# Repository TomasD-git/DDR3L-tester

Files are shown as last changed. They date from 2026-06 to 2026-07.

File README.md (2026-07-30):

# DDR3L-tester  
**Very simple DDR3L tester, plug ddr3l stick into slot, esp32 c6 reads data and can overwrite config of ram as well, with buttons for control and screen to see progress**  

<details>
<summary>How to make one?</summary>
  
**Either buy PCBA which is much easier but much more expenisve, or buy all parts and assemble with hotplate or hotair gun. all files needed for this are in production folder**  

</details>

<details>
<summary>How assemble?</summary>
Place top part ontop of the pcb and solder screen and buttons, then place the bottom part underneath the pcb and use M2 screws to screw into place.  

</details>

<details>
<summary>How to flash?</summary>
Plug the USB-C into computer and use arduino ide to flash.  

</details>

<details>
<summary>BOM</summary>

| Name | Purpose | Quantity | Total Cost (USD) | Link | Distributor |
| --- | --- | --- | --- | --- | --- |
| PCB + stencil if needed | all components are on this | 1 | 20 | https://jlcpcb.com | jlcpcb |
| ALL components | all components that are on pcb | 1 | 40 | https://lcsc.com | lcsc |
| Screen | shows info numbers etc.. | 1 | 3 | https://www.aliexpress.com/item/1005006141235306.html | Aliexpress |
| | | **Total cost** | **63** | | |

</details>

    
  
  
  


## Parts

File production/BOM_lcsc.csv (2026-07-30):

JLCPCB BOM Tool - BOM Matching
BOM name：bom-JLCPCB Assembly Order.xlsx |  |  | Download Time：2026-06-09 15:07:55 |  |  |  | * Our matching results are updated in real-time, but stock and prices may change. If it's been over 24 hours, please re-match before placing your order.
PCB Assembled Qty：5 |  |  | Est. Total Price：46.1511
Your BOM |  |  |  |  | Matched Parts |  |  |  |  |  |  | Order Information
Top Designator | Bottom Designator | Comment | Footprint | JLCPCB Part # | Matches | Part # | Manufacturer | Footprint | Description | Category | Warning | JLCPCB Part # | Product link | Lib Type | Qty | Source | Total Price ($)
C1,C10,C19,C20,C5 |  | 100nF | 0805 |  | Select by System | CC0805KRX7R9BB104 | YAGEO | 0805 | 100nF 50V X7R ±10% 0805 Multilayer Ceramic Capacitors MLCC - SMD/SMT ROHS | Multilayer Ceramic Capacitors MLCC - SMD/SMT |  | C49678 | https://jlcpcb.com/partdetail/YAGEO-CC0805KRX7R9BB104/C49678 | Basic | 35 | 35 JLCPCB | 0.2975
C2 |  | 47uF | 1210 |  | Select by System | CS3225X7R476K100NRL | Samwha Capacitor | 1210 | 10V 47uF X7R ±10% 1210 Multilayer Ceramic Capacitors MLCC - SMD/SMT ROHS | Multilayer Ceramic Capacitors MLCC - SMD/SMT |  | C5189825 | https://jlcpcb.com/partdetail/5869646-CS3225X7R476K100NRL/C5189825 | Extended | 9 | 9 JLCPCB | 0.8595
C3,C7 |  | 10uF | 0805 |  | Select by System | GRM21BR61H106KE43L | Murata Electronics | 0805 | 10uF 50V X5R ±10% 0805 Multilayer Ceramic Capacitors MLCC - SMD/SMT ROHS | Multilayer Ceramic Capacitors MLCC - SMD/SMT |  | C440198 | https://jlcpcb.com/partdetail/439567-GRM21BR61H106KE43L/C440198 | Basic | 10 | 10 JLCPCB | 3.083
C8,C9 |  | 1nF | 0805 |  | Select by System | CL21B102KBCNNNC | Samsung Electro-Mechanics | 0805 | 1nF 50V X7R ±10% 0805 Multilayer Ceramic Capacitors MLCC - SMD/SMT ROHS | Multilayer Ceramic Capacitors MLCC - SMD/SMT |  | C46653 | https://jlcpcb.com/partdetail/47657-CL21B102KBCNNNC/C46653 | Basic | 20 | 20 JLCPCB | 0.224
C21,C4,C6 |  | 1uF | 0805 |  | Select by System | CL21B105KBFNNNE | Samsung Electro-Mechanics | 0805 | 1uF 50V X7R ±10% 0805 Multilayer Ceramic Capacitors MLCC - SMD/SMT ROHS | Multilayer Ceramic Capacitors MLCC - SMD/SMT |  | C28323 | https://jlcpcb.com/partdetail/29074-CL21B105KBFNNNE/C28323 | Basic | 25 | 25 JLCPCB | 0.4325
D1 |  | GREENLED | LED_D5.0mm |  | Select by Customer | TJ-L5FYTGHKMCGLFLC7K-A5 | TOGIALED | 插件,D=5mm | -20℃~+80℃ 1.8V~2.6V 20mA 45° 565nm~575nm 575nm 5mm round lamp head 60mcd 72mW Green Diffused Lens Yellow Green 插件,D=5mm LED Indication - Discrete ROHS | LED Indication - Discrete |  | C330740 | https://jlcpcb.com/partdetail/TOGIALED-TJ_L5FYTGHKMCGLFLC7KA5/C330740 | Extended | 6 | 6 JLCPCB | 0.2502
D2 |  | REDLED | LED_D5.0mm |  | Select by Customer | 333-2SURD/S530-A3 | Everlight Elec | 插件,D=5mm | -40℃~+85℃ 200mcd 20mA 2V 30° 5mm round lamp head 624nm 632nm Red Red Lens 插件,D=5mm LED Indication - Discrete ROHS | LED Indication - Discrete |  | C87271 | https://jlcpcb.com/partdetail/EverlightElec-333_2SURD_S530A3/C87271 | Extended | 10 | 10 JLCPCB | 0.417
R1,R10,R9 |  | 10K | 0805 |  | Unconfirmed | 0805W8F1002T5E | UNI-ROYAL(Uniroyal Elec) | 0805 | -55℃~+155℃ 10kΩ 125mW 150V Thick Film Resistor ±1% ±100ppm/℃ 0805 Chip Resistor - Surface Mount ROHS | Chip Resistor - Surface Mount | 1.The comment (0805W8F1002T5E) of this part does not match the one (10K) provided in your BOM. Please confirm; | C17414 | https://jlcpcb.com/partdetail/18102-0805W8F1002T5E/C17414 | Basic | 25 | 25 JLCPCB | 0.0725
R2,R3 |  | 330 | 0805 |  | Unconfirmed | 0805W8F3300T5E | UNI-ROYAL(Uniroyal Elec) | 0805 | -55℃~+155℃ 125mW 150V 330Ω Thick Film Resistor ±1% ±100ppm/℃ 0805 Chip Resistor - Surface Mount ROHS | Chip Resistor - Surface Mount | 1.The comment (0805W8F3300T5E) of this part does not match the one (330) provided in your BOM. Please confirm; | C17630 | https://jlcpcb.com/partdetail/18318-0805W8F3300T5E/C17630 | Basic | 20 | 20 JLCPCB | 0.054
R11,R12 |  | 22 | 0805 |  | Unconfirmed | 0805W8F220JT5E | UNI-ROYAL(Uniroyal Elec) | 0805 | -55℃~+155℃ 125mW 150V 22Ω Thick Film Resistor ±1% ±100ppm/℃ 0805 Chip Resistor - Surface Mount ROHS | Chip Resistor - Surface Mount | 1.The comment (0805W8F220JT5E) of this part does not match the one (22) provided in your BOM. Please confirm; | C17561 | https://jlcpcb.com/partdetail/18249-0805W8F220JT5E/C17561 | Basic | 20 | 20 JLCPCB | 0.054
R13,R14 |  | 5.1K | 0805 |  | Unconfirmed | 0805W8F5101T5E | UNI-ROYAL(Uniroyal Elec) | 0805 | -55℃~+155℃ 125mW 150V 5.1kΩ Thick Film Resistor ±1% ±100ppm/℃ 0805 Chip Resistor - Surface Mount ROHS | Chip Resistor - Surface Mount | 1.The comment (0805W8F5101T5E) of this part does not match the one (5.1K) provided in your BOM. Please confirm; | C27834 | https://jlcpcb.com/partdetail/28584-0805W8F5101T5E/C27834 | Basic | 20 | 20 JLCPCB | 0.054
R15,R16 |  | 4.7K | 0805 |  | Unconfirmed | 0805W8F4701T5E | UNI-ROYAL(Uniroyal Elec) | 0805 | -55℃~+155℃ 125mW 150V 4.7kΩ Thick Film Resistor ±1% ±100ppm/℃ 0805 Chip Resistor - Surface Mount ROHS | Chip Resistor - Surface Mount | 1.The comment (0805W8F4701T5E) of this part does not match the one (4.7K) provided in your BOM. Please confirm; | C17673 | https://jlcpcb.com/partdetail/18361-0805W8F4701T5E/C17673 | Basic | 20 | 20 JLCPCB | 0.044
SW1,SW2 |  | SW_Push | SW_PUSH_6mm |  | Select by Customer | TC-00104-050E | HOOYA | 插件,6x6mm | 2.5N 5mm 6mm 6mm Black No PC Pin Round Button SPST Through Hole Without Bracket Plugin,6x6mm Tactile Switches ROHS | Tactile Switches |  | C2939600 | https://jlcpcb.com/partdetail/HOOYA-TC_00104050E/C2939600 | Extended | 10 | 10 JLCPCB | 0.229
SW3 |  | RotaryEncoder_Switch_MP | RotaryEncoder_Alps_EC11E-Switch_Vertical_H20mm |  | Select by Customer | EC11E1834403 | ALPSALPINE | 插件 | -40℃~+85℃ 10mA 5V Non-resettable Straight Support Two-phase output 插件 Rotary Encoders ROHS | Rotary Encoders |  | C361165 | https://jlcpcb.com/partdetail/ALPSALPINE-EC11E1834403/C361165 | Extended | 5 | 5 JLCPCB | 10.1695
SW6 |  | SS-12D00-G4E | 1P2T_SS-12D00_CNK |  | Select by Customer | SS-12D00-G3 | SOFNG | 插件-3P,8.8x3.9mm | -35℃~+75℃ 3.9mm 7.2mm 8.8mm Black PC Pin Rectangular Columnar SPDT Through Hole 插件-3P,8.8x3.9mm Slide Switches ROHS | Slide Switches |  | C22355741 | https://jlcpcb.com/partdetail/SOFNG-SS_12D00G3/C22355741 | Extended | 6 | 6 JLCPCB | 0.351
U2 |  | XDAP-4042044-20401 | CONN-SMD_204P-P0.60_XDAP-4042044-20401 |  | Select by System | XDAP-4042044-20401 | Lian Xin Technology | SMD | 204P 5.2mm DDR3 SO-DIMM Surface Mount SMD Memory Connector (DDR) ROHS | Memory Connector (DDR) |  | C22471982 | https://jlcpcb.com/partdetail/24195375-XDAP_404204420401/C22471982 | Extended | 5 | 5 JLCPCB | 7.78
U3 |  | AP2112K-3.3TRG1 | SOT-25-5_L2.9-W1.6-P0.95-LS2.8-BL |  | Select by System | AP2112K-3.3TRG1 | Diodes Incorporated | SOT-25-5 | -40℃~+85℃@(Ta) 1 250mV@(600mA) 3.3V 50uVrms 55uA 600mA 65dB@(1kHz) 6V Fixed Over Current Protection、Thermal Shutdown、Enable control Positive SOT-25-5 Voltage Regulators - Linear, Low Drop Out (LDO) Regulators ROHS | Voltage Regulators - Linear, Low Drop Out (LDO) Regulators |  | C51118 | https://jlcpcb.com/partdetail/DiodesIncorporated-AP2112K_33TRG1/C51118 | Extended | 7 | 7 JLCPCB | 1.1375
U4 |  | ESP32-C6-MINI-1/U | ESP32-C6-MINI-1 |  | Select by Customer | ESP32-C6-MINI-1-N4 | Espressif Systems | SMD-53P | -106dBm -40℃~+85℃ 2.4GHz 21dBm 354mA 3V~3.6V 71mA ESP32-C6FH4 On-board PCB Antenna UART、SPI、I2C、GPIO、I2S SMD-53P WiFi Modules ROHS | WiFi Modules |  | C5736265 | https://jlcpcb.com/partdetail/EspressifSystems-ESP32_C6_MINI_1N4/C5736265 | Extended | 5 | 5 JLCPCB | 20.2015
USB1 |  | TYPE-C16PIN2MD | USB-C-SMD_TYPE-C-16PIN-2MD-073 |  | Select by System | TYPE-C 16PIN 2MD(073) | SHOU HAN | SMD | -25℃~+85℃ 1 16P 3A 5,000 times 5V Black Female Surface Mount, Right Angle Type-C SMD USB Connectors ROHS | USB Connectors |  | C2765186 | https://jlcpcb.com/partdetail/SHOUHAN-TYPE_C_16PIN_2MD_073/C2765186 | Extended | 6 | 6 JLCPCB | 0.4404
J1 |  | 128x64LCDDisplay | PinSocket_1x04_P2.54mm_Vertical |  | No matches | No Part Selected
SW4,SW5 |  | SW_Push | SW_Cherry_MX_1.00u_PCB |  | No matches | No Part Selected

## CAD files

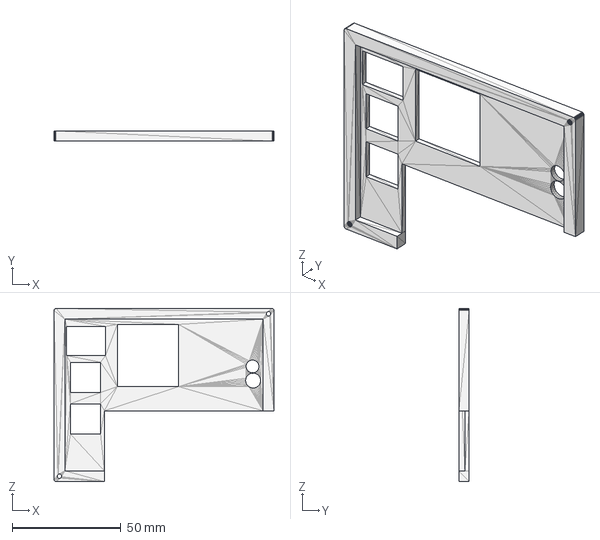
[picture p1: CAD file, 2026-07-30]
CAD/Top.step
101.3 x 4.75 x 79.8 mm

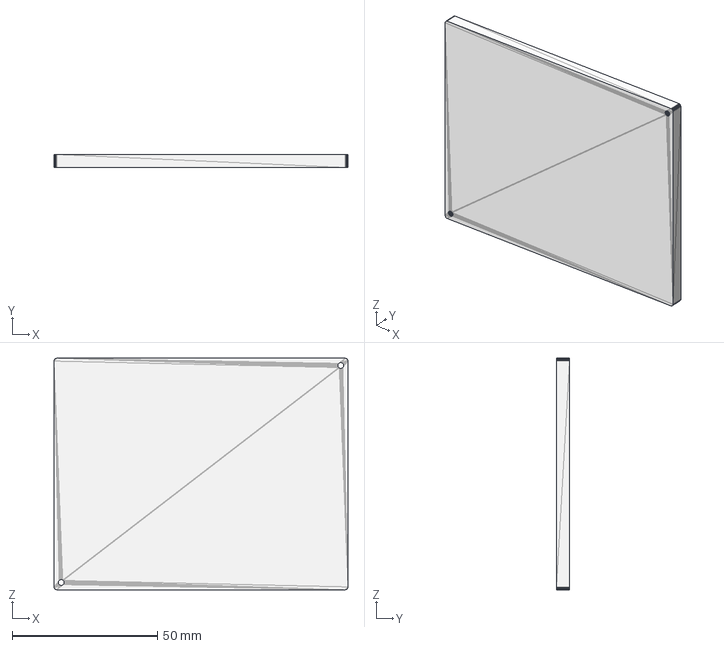
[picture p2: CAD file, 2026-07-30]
CAD/Bottom.step
101.3 x 4.50 x 79.8 mm

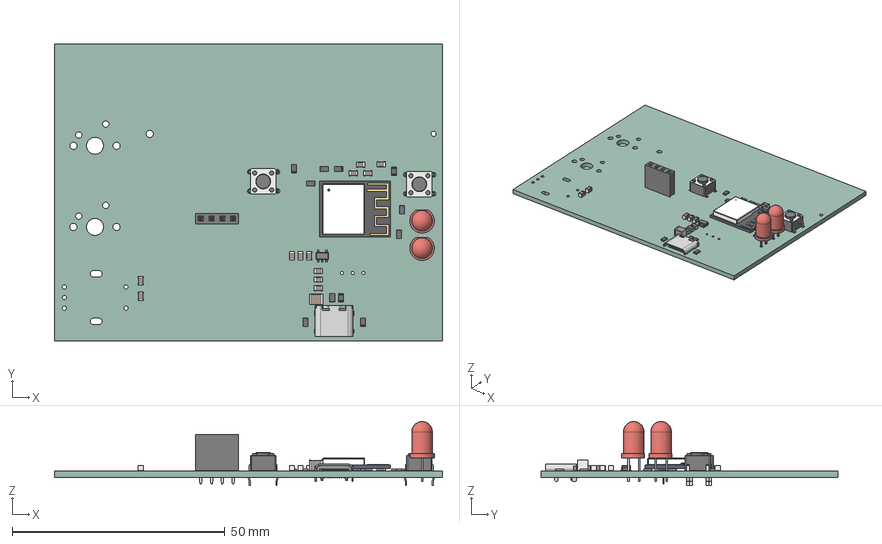
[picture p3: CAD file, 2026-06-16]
CAD/DDR3 tester PCB.step
91.3 x 69.8 x 15.1 mm
LED_D5.0mm x 2
R_0805_2012Metric x 11
C_0805_2012Metric x 12
SOT-25-5_L2.9-W1.6-P0.95-LS2.8-BL
uid__2428
R0201_20210301.xtd x 3
L0201_20210301.xtd x 2
C0201_20210301.xtd x 10
ESP32-C6_QFN32_5X5_202306.xtd
XTAL3225_20210301.xtd
DFN1006.xtd
C0402_20210301.xtd
placementOutline_18
placementOutline_19
placementOutline_20
placementOutline_21
placementOutline_22
placementOutline_23
placementOutline_24
MINI-ANT-TYPE-D-H-top
MINI-ANT-TYPE-D-H-buttom
C3-MINI-solder_pad
ShieldBox_ESP32-C3-MINI-1_V1.0_20200901
PinSocket_1x04_P2.54mm_Vertical
C_1210_3225Metric
SW_PUSH_6mm x 2
USB-C-SMD_TYPE-C-6PIN-2MD-073
DDR3 tester_PCB

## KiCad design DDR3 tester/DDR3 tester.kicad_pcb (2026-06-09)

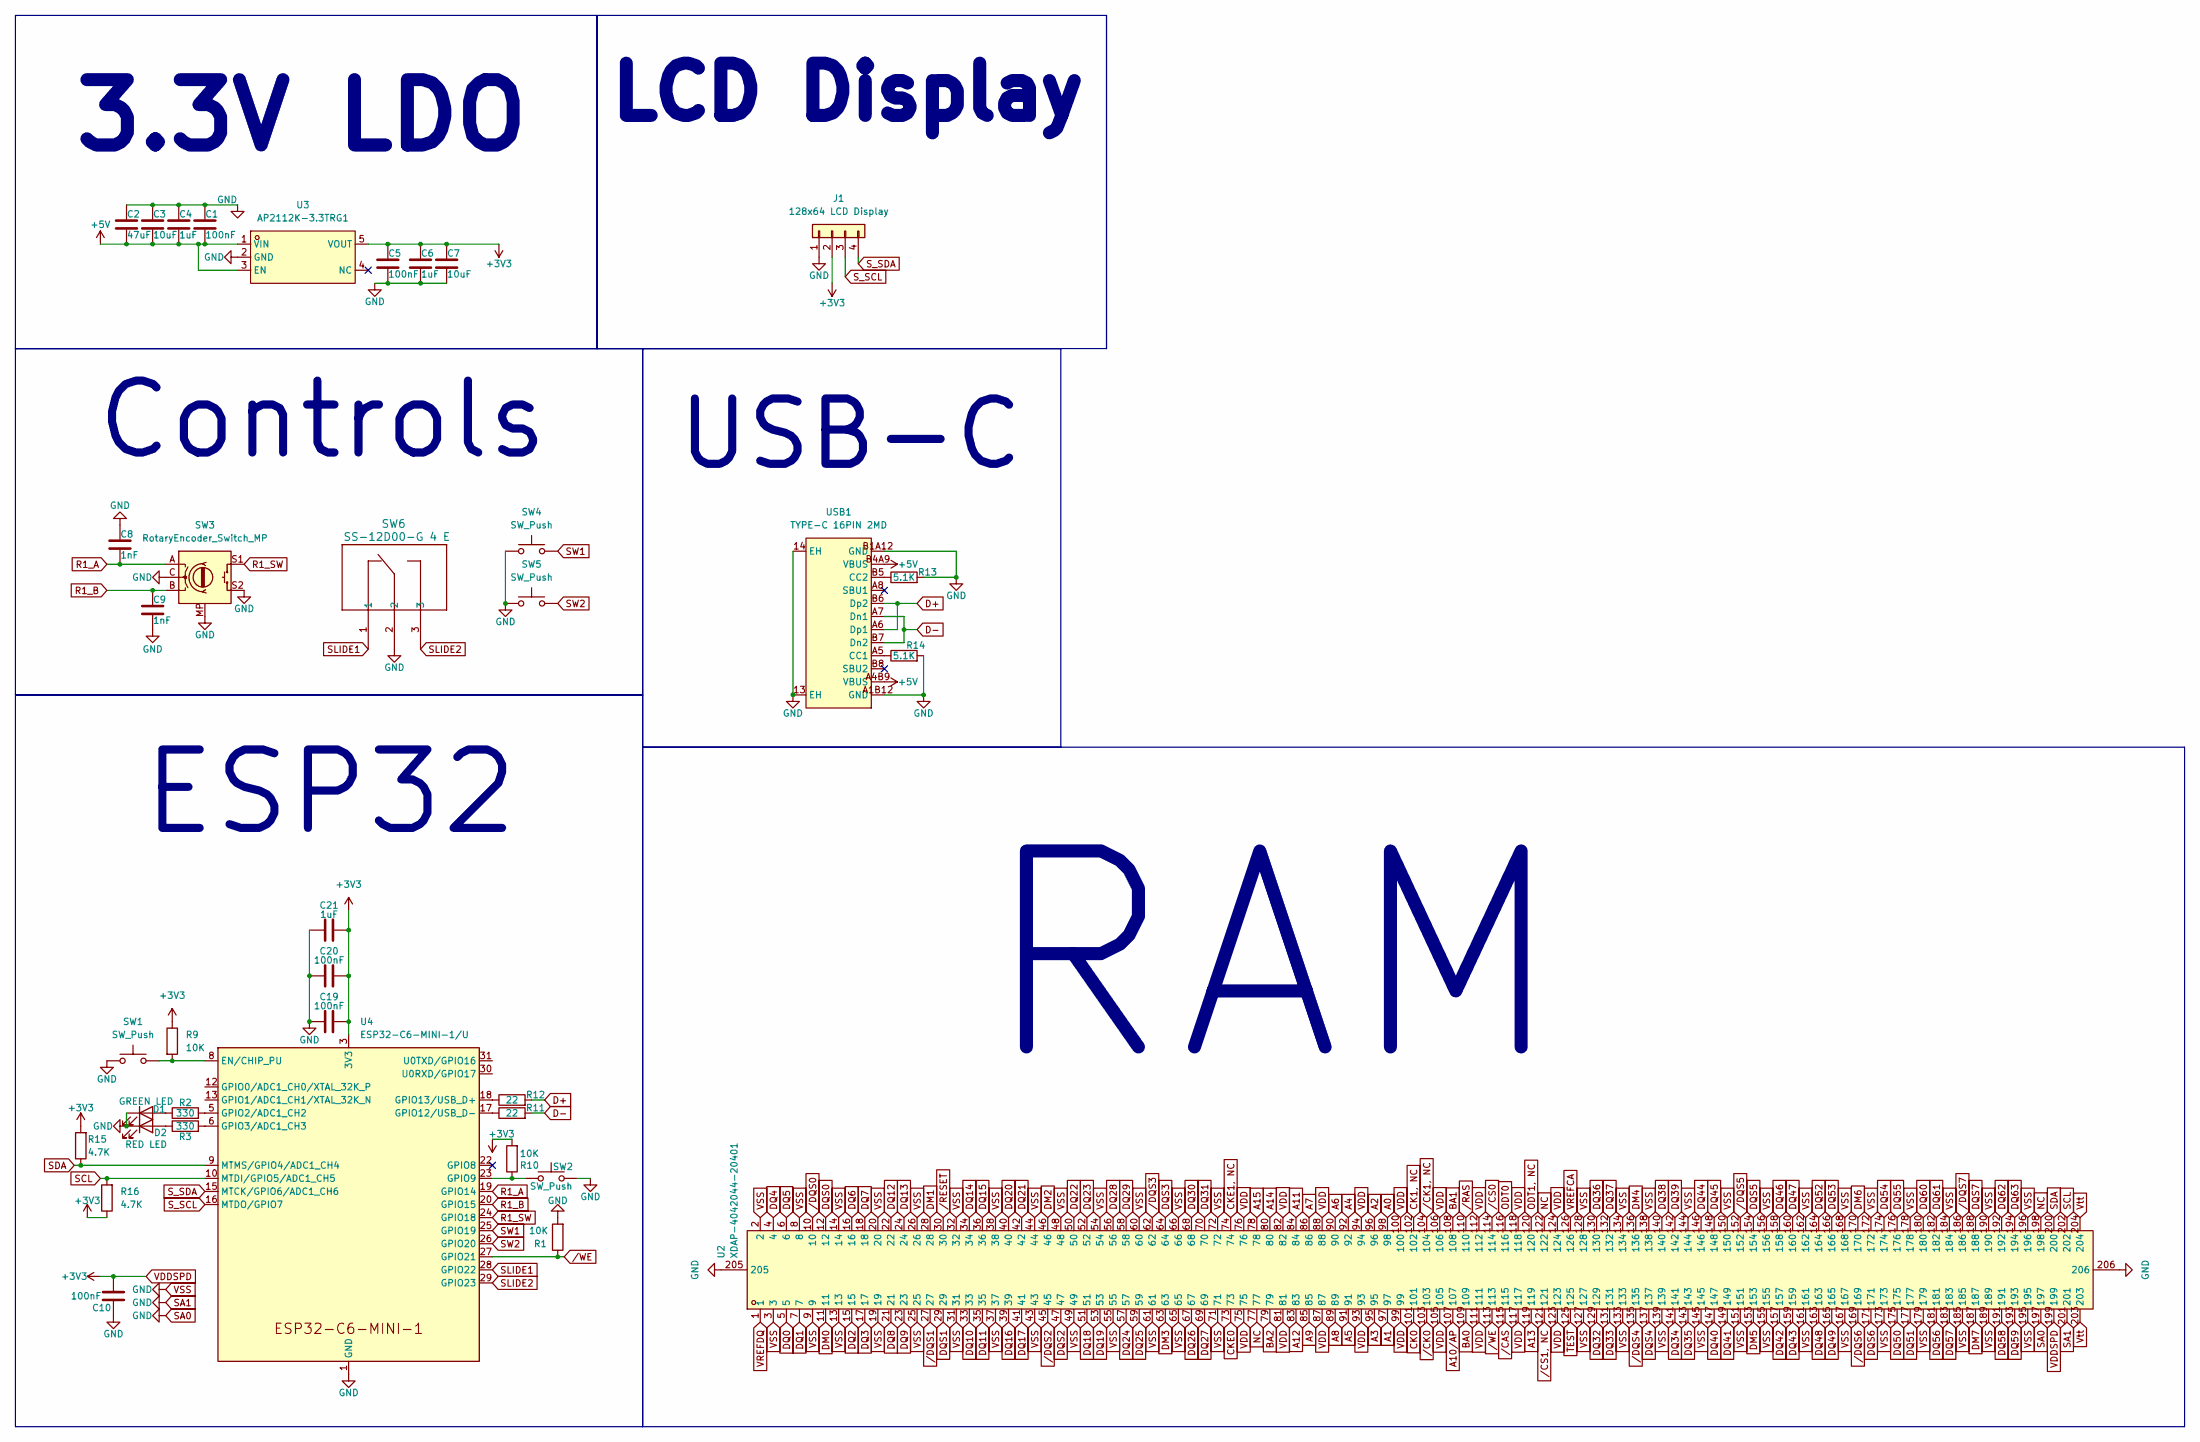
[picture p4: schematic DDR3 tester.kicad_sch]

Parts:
C1, C5, C10, C19, C20: 100nF; C_0805_2012Metric
C2: 47uF; C_1210_3225Metric
C3, C7: 10uF; C_0805_2012Metric
C4, C6, C21: 1uF; C_0805_2012Metric
C8, C9: 1nF; C_0805_2012Metric
D1: GREEN LED; LED_D5.0mm
D2: RED LED; LED_D5.0mm
J1: 128x64 LCD Display; PinSocket_1x04_P2.54mm_Vertical
R1, R9, R10: 10K; R_0805_2012Metric
R2, R3: 330; R_0805_2012Metric
R11, R12: 22; R_0805_2012Metric
R13, R14: 5.1K; R_0805_2012Metric
R15, R16: 4.7K; R_0805_2012Metric
SW1, SW2: SW_Push; SW_PUSH_6mm
SW3: RotaryEncoder_Switch_MP; RotaryEncoder_Alps_EC11E-Switch_Vertical_H20mm
SW4, SW5: SW_Push; SW_Cherry_MX_1.00u_PCB
SW6: SS-12D00-G 4 E; 1P2T_SS-12D00_CNK
U2: XDAP-4042044-20401; CONN-SMD_204P-P0.60_XDAP-4042044-20401; MPN XDAP-4042044-20401; LCSC Part C22471982
U3: AP2112K-3.3TRG1; SOT-25-5_L2.9-W1.6-P0.95-LS2.8-BL; MPN AP2112K-3.3TRG1; LCSC Part C51118
U4: ESP32-C6-MINI-1/U; ESP32-C6-MINI-1
USB1: TYPE-C 16PIN 2MD; USB-C-SMD_TYPE-C-16PIN-2MD-073; MPN TYPE-C 16PIN 2MD(073); LCSC Part C2765186

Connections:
+5V: C1.2, C2.1, C3.1, C4.2, U3.1 (VIN), U3.3 (EN), USB1.A4B9 (VBUS), USB1.B4A9 (VBUS)
A0: U2.98
A1: U2.97
A2: U2.96
A3: U2.95
A4: U2.92
A5: U2.91
A6: U2.90
A7: U2.86
A8: U2.89
A9: U2.85
A10/AP: U2.107
A11: U2.84
A12: U2.83
A13: U2.119
A14: U2.80
A15: U2.78
BA0: U2.109
BA1: U2.108
BA2: U2.79
CK0: U2.101
CK1, NC: U2.102
CKE0: U2.73
CKE1, NC: U2.74
D+: R12.2, USB1.A6 (Dp1), USB1.B6 (Dp2)
D-: R11.2, USB1.A7 (Dn1), USB1.B7 (Dn2)
DM0: U2.11
DM1: U2.28
DM2: U2.46
DM3: U2.63
DM4: U2.136
DM5: U2.153
DM6: U2.170
DM7: U2.187
DQ0: U2.5
DQ1: U2.7
DQ2: U2.15
DQ3: U2.17
DQ4: U2.4
DQ5: U2.6
DQ6: U2.16
DQ7: U2.18
DQ8: U2.21
DQ9: U2.23
DQ10: U2.33
DQ11: U2.35
DQ12: U2.22
DQ13: U2.24
DQ14: U2.34
DQ15: U2.36
DQ16: U2.39
DQ17: U2.41
DQ18: U2.51
DQ19: U2.53
DQ20: U2.40
DQ21: U2.42
DQ22: U2.50
DQ23: U2.52
DQ24: U2.57
DQ25: U2.59
DQ26: U2.67
DQ27: U2.69
DQ28: U2.56
DQ29: U2.58
DQ30: U2.68
DQ31: U2.70
DQ32: U2.129
DQ33: U2.131
DQ34: U2.141
DQ35: U2.143
DQ36: U2.130
DQ37: U2.132
DQ38: U2.140
DQ39: U2.142
DQ40: U2.147
DQ41: U2.149
DQ42: U2.157
DQ43: U2.159
DQ44: U2.146
DQ45: U2.148
DQ46: U2.158
DQ47: U2.160
DQ48: U2.163
DQ49: U2.165
DQ50: U2.175
DQ51: U2.177
DQ52: U2.164
DQ53: U2.166
DQ54: U2.174
DQ55: U2.176
DQ56: U2.181
DQ57: U2.183
DQ58: U2.191
DQ59: U2.193
DQ60: U2.180
DQ61: U2.182
DQ62: U2.192
DQ63: U2.194
DQS0: U2.12
DQS1: U2.29
DQS2: U2.47
DQS3: U2.64
DQS4: U2.137
DQS5: U2.154
DQS6: U2.171
DQS7: U2.188
NC: U2.77, U2.122, U2.198
unnamed: D1.2 (A), R2.1
unnamed: D2.2 (A), R3.1
unnamed: R9.2, SW1.2, U4.8 (EN/CHIP_PU)
unnamed: R2.2, U4.5 (GPIO2/ADC1_CH2)
unnamed: R3.2, U4.6 (GPIO3/ADC1_CH3)
unnamed: R10.1, SW2.1, U4.23 (GPIO9)
unnamed: R11.1, U4.17 (GPIO12/USB_D-)
unnamed: R12.1, U4.18 (GPIO13/USB_D+)
unnamed: R14.1, USB1.A5 (CC1)
unnamed: R13.1, USB1.B5 (CC2)
ODT0: U2.116
ODT1, NC: U2.120
R1_A: C8.2, SW3.A, U4.19 (GPIO14)
R1_B: C9.1, SW3.B, U4.20 (GPIO15)
R1_SW: SW3.S1, U4.24 (GPIO18)
SA0: C1.1, C2.2, C3.2, C4.1, C5.2, C6.2, C7.2, C8.1, C9.2, C10.1, C19.1, C20.1, C21.1, D1.1 (K), D2.1 (K), J1.1, R1.2, R13.2, R14.2, SW1.1, SW2.2, SW3.C, SW3.MP, SW3.S2, SW4.1, SW5.1, SW6.2, U2.2, U2.3, U2.8, U2.9, U2.13, U2.14, U2.19, U2.20, U2.25, U2.26, U2.31, U2.32, U2.37, U2.38, U2.43, U2.44, U2.48, U2.49, U2.54, U2.55, U2.60, U2.61, U2.65, U2.66, U2.71, U2.72, U2.127, U2.128, U2.133, U2.134, U2.138, U2.139, U2.144, U2.145, U2.150, U2.151, U2.155, U2.156, U2.161, U2.162, U2.167, U2.168, U2.172, U2.173, U2.178, U2.179, U2.184, U2.185, U2.189, U2.190, U2.195, U2.196, U2.197, U2.201, U2.205, U2.206, U3.2 (GND), U4.1 (GND), U4.2 (GND), U4.11 (GND), U4.14 (GND), U4.36 (GND), U4.37 (GND), U4.38 (GND), U4.39 (GND), U4.40 (GND), U4.41 (GND), U4.42 (GND), U4.43 (GND), U4.44 (GND), U4.45 (GND), U4.46 (GND), U4.47 (GND), U4.48 (GND), U4.49 (GND), U4.50 (GND), U4.51 (GND), U4.52 (GND), U4.53 (GND), USB1.13 (EH), USB1.14 (EH), USB1.A1B12 (GND), USB1.B1A12 (GND)
SCL: R16.2, U2.202, U4.10 (MTDI/GPIO5/ADC1_CH5)
SDA: R15.1, U2.200, U4.9 (MTMS/GPIO4/ADC1_CH4)
SLIDE1: SW6.1, U4.28 (GPIO22)
SLIDE2: SW6.3, U4.29 (GPIO23)
SW1: SW4.2, U4.25 (GPIO19)
SW2: SW5.2, U4.26 (GPIO20)
S_SCL: J1.3, U4.16 (MTDO/GPIO7)
S_SDA: J1.4, U4.15 (MTCK/GPIO6/ADC1_CH6)
TEST: U2.125
VDD: U2.75, U2.76, U2.81, U2.82, U2.87, U2.88, U2.93, U2.94, U2.99, U2.100, U2.105, U2.106, U2.111, U2.112, U2.117, U2.118, U2.123, U2.124
VDDSPD: C5.1, C6.1, C7.1, C10.2, C19.2, C20.2, C21.2, J1.2, R9.1, R10.2, R15.2, R16.1, U2.199, U3.5 (VOUT), U4.3 (3V3)
VREFCA: U2.126
VREFDQ: U2.1
Vtt: U2.203, U2.204
/CAS: U2.115
/CK0: U2.103
/CK1, NC: U2.104
/CS0: U2.114
/CS1, NC: U2.121
/DQS0: U2.10
/DQS1: U2.27
/DQS2: U2.45
/DQS3: U2.62
/DQS4: U2.135
/DQS5: U2.152
/DQS6: U2.169
/DQS7: U2.186
/RAS: U2.110
/RESET: U2.30
/WE: R1.1, U2.113, U4.27 (GPIO21)

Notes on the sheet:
RAM
LCD Display
Controls
USB-C
3.3V LDO
ESP32

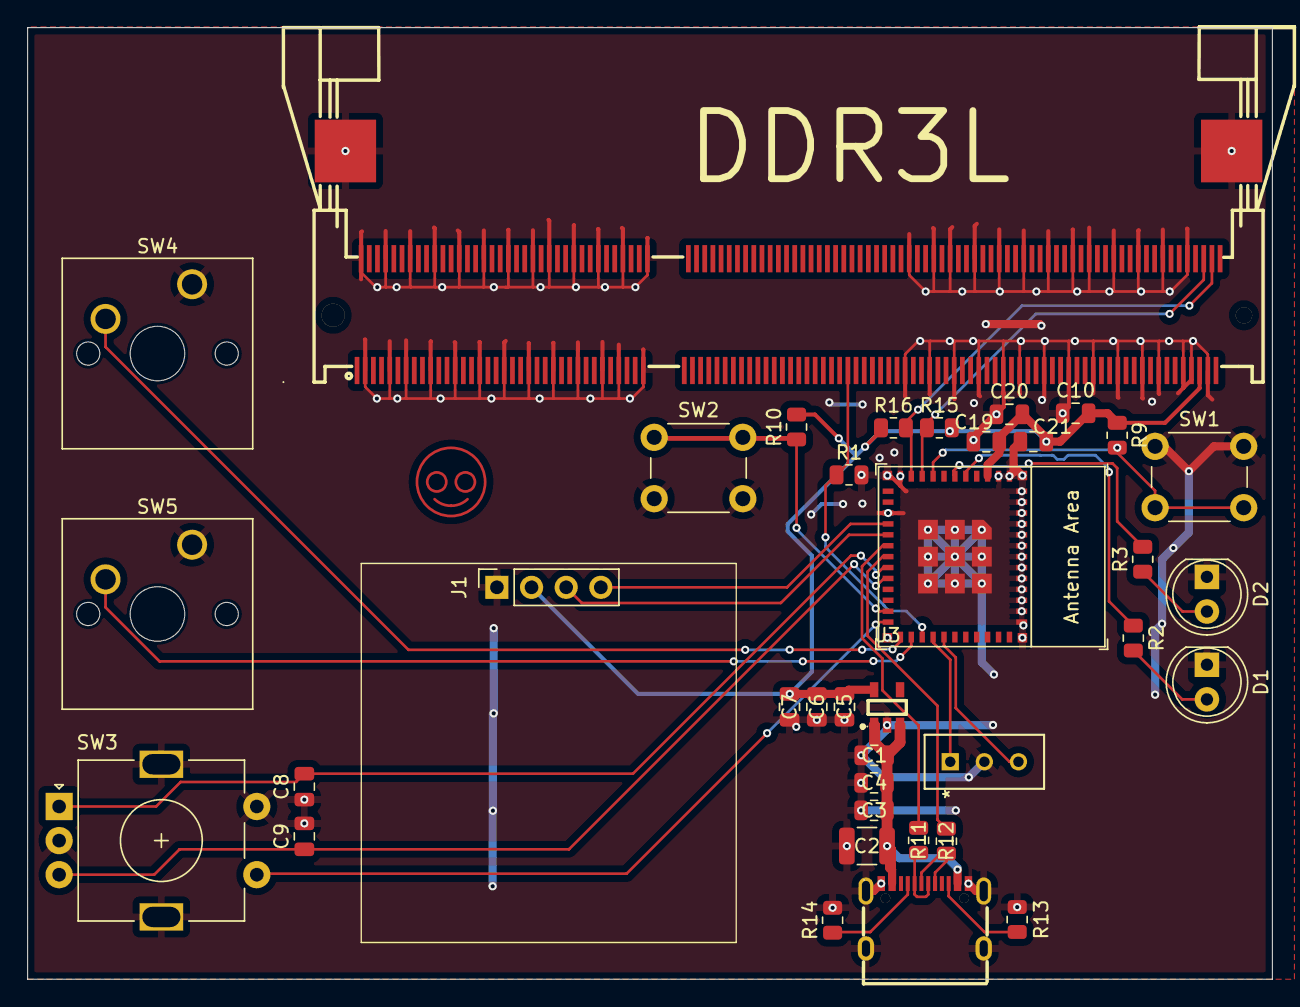
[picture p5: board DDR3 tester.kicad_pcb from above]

Board: 2 copper layers, 91.3 x 69.8 mm, 37 parts (0 on the bottom side), 30 nets.

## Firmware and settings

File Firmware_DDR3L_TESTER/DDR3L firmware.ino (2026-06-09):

#include <Arduino.h>
#include <Wire.h>
#include <U8g2lib.h>

#define PIN_ROT_A      14   
#define PIN_ROT_B      15  
#define PIN_ROT_SW     18 
#define PIN_BTN_SEL    19   
#define PIN_BTN_ABORT  20   
#define PIN_SLIDE1     22  
#define PIN_SLIDE2     23   
#define PIN_WE         21   

#define SDA_LCD  6
#define SCL_LCD  7
#define SDA_SPD  4
#define SCL_SPD  5

TwoWire spdBus(1);   

U8G2_SSD1306_128X64_NONAME_F_HW_I2C lcd(
    U8G2_R0, U8X8_PIN_NONE, SCL_LCD, SDA_LCD);

#define SPD_EEPROM_ADDR 0x50
#define SPD_SIZE        256

#define SPD_DRAM_TYPE   2   
#define SPD_MODULE_TYPE 3   
#define SPD_DENSITY     4   
#define SPD_ADDRESSING  5   
#define SPD_VOLTAGE     6   
#define SPD_ORG         7   
#define SPD_BUS_WIDTH   8   
#define SPD_TCK_MIN     12 
#define SPD_CL_LSB      14 
#define SPD_CL_MSB      15  
#define SPD_TAA_MIN     16  
#define SPD_TWR_MIN     17 
#define SPD_TRCD_MIN    18 
#define SPD_TRRD_MIN    19 
#define SPD_TRP_MIN     20  
#define SPD_TRAS_UPP    21 
#define SPD_TRAS_LSB    22 
#define SPD_TRC_LSB     23 
#define SPD_MFR_LSB     117
#define SPD_MFR_MSB     118
#define SPD_PART_NUM    128 

uint8_t spdOrig[SPD_SIZE];   
uint8_t spdEdit[SPD_SIZE];  

struct Param {
  const char *label;   
  uint8_t     idx;     
  uint8_t     minV;
  uint8_t     maxV;
  uint8_t     step;
};

static const Param PARAMS[] = {
  { "tCK (spd)",  SPD_TCK_MIN,   8,  30,  1 }, 
  { "tAA  (CL)",  SPD_TAA_MIN,   5,  30,  1 },
  { "tRCD",       SPD_TRCD_MIN,  5,  30,  1 },
  { "tRP",        SPD_TRP_MIN,   5,  30,  1 },
  { "tRAS",       SPD_TRAS_LSB, 20, 200,  2 },
  { "tRC",        SPD_TRC_LSB,  20, 255,  2 },
  { "tRRD",       SPD_TRRD_MIN,  4,  30,  1 },
  { "tWR",        SPD_TWR_MIN,   5,  30,  1 },
};
static const int N_PARAMS = (int)(sizeof(PARAMS) / sizeof(PARAMS[0]));

volatile int rotPos      = 0;
volatile int lastEncoded = 0;

void IRAM_ATTR rotISR() {
  int a   = digitalRead(PIN_ROT_A);
  int b   = digitalRead(PIN_ROT_B);
  int enc = (a << 1) | b;
  int sum = (lastEncoded << 2) | enc;
  if (sum == 0b1101 || sum == 0b0100 || sum == 0b0010 || sum == 0b1011) rotPos++;
  if (sum == 0b1110 || sum == 0b0111 || sum == 0b0001 || sum == 0b1000) rotPos--;
  lastEncoded = enc;
}

struct Button {
  uint8_t pin;
  bool    lastState    = true;  
  bool    wasPressed   = false;  
  unsigned long holdStart = 0;
  void update() {
    bool cur = (digitalRead(pin) == LOW);
    wasPressed = cur && !lastState;
    if (wasPressed) holdStart = millis();
    lastState  = cur;
  }
  bool heldFor(uint32_t ms) const {
    return (digitalRead(pin) == LOW) && holdStart && (millis() - holdStart >= ms);
  }
  bool isDown() const { return digitalRead(pin) == LOW; }
};

Button btnSel   = { PIN_BTN_SEL   };
Button btnAbort = { PIN_BTN_ABORT };
Button btnRot   = { PIN_ROT_SW   };

static int lastRotPos = 0;
int rotDelta() {
  int d = rotPos - lastRotPos;
  lastRotPos = rotPos;
  return d;
}

uint16_t tckToMTps(uint8_t tck) {
  return tck ? (uint16_t)(16000u / tck) : 0;
}

uint16_t calcCapMB(const uint8_t *s) {
  static const uint16_t dieMb[] = { 256, 512, 1024, 2048, 4096, 8192 };
  uint8_t dieIdx = s[SPD_DENSITY] & 0x0F;
  if (dieIdx < 1 || dieIdx > 6) return 0;
  uint16_t dieCap = dieMb[dieIdx - 1];
  uint8_t devW  = 4u << (s[SPD_ORG]       & 0x07);  
  uint8_t ranks = 1u + ((s[SPD_ORG] >> 3) & 0x07);
  uint8_t busW  = 8u << (s[SPD_BUS_WIDTH] & 0x07);   
  return (uint32_t)dieCap * busW / devW * ranks / 8;
}

void getPartNum(const uint8_t *s, char *buf, size_t bufLen) {
  size_t n = min((size_t)18, bufLen - 1);
  for (size_t i = 0; i < n; i++) {
    char c = (char)s[SPD_PART_NUM + i];
    buf[i] = (c >= 0x20 && c < 0x7F) ? c : ' ';
  }
  int end = (int)n - 1;
  while (end >= 0 && buf[end] == ' ') end--;
  buf[end + 1] = '\0';
}

bool spdDetect() {
  spdBus.beginTransmission(SPD_EEPROM_ADDR);
  return spdBus.endTransmission() == 0;
}

bool spdRead(uint8_t *buf) {
  for (int pg = 0; pg < 2; pg++) {
    spdBus.beginTransmission(0x36 + pg);
    if (spdBus.endTransmission() != 0) return false;
    delayMicroseconds(500);
    spdBus.beginTransmission(SPD_EEPROM_ADDR);
    spdBus.write((uint8_t)0x00);
    if (spdBus.endTransmission(false) != 0) return false;
    uint8_t got = spdBus.requestFrom((uint8_t)SPD_EEPROM_ADDR, (uint8_t)128);
    if (got < 128) return false;
    for (int i = 0; i < 128; i++) buf[pg * 128 + i] = spdBus.read();
  }
  spdBus.beginTransmission(0x36);
  spdBus.endTransmission();
  return (buf[SPD_DRAM_TYPE] == 0x0B);   
}

bool spdWriteChanges(const uint8_t *orig, const uint8_t *edit) {
  spdBus.beginTransmission(0x36);
  spdBus.endTransmission();
  delay(2);
  for (int i = 0; i < 128; i++) {
    if (edit[i] == orig[i]) continue;
    spdBus.beginTransmission(SPD_EEPROM_ADDR);
    spdBus.write((uint8_t)i);
    spdBus.write(edit[i]);
    if (spdBus.endTransmission() != 0) return false;
    delay(6);   
  }
  return true;
}
#define FONT_MD  u8g2_font_6x10_tf    
#define FONT_LG  u8g2_font_10x20_tf  
#define FONT_XS  u8g2_font_5x7_tf    
void drawHeader(const char *title) {
  lcd.setFont(FONT_MD);
  lcd.drawStr(0, 10, title);
  lcd.drawHLine(0, 12, 128);
}

void screenNoDDR() {
  lcd.clearBuffer();
  drawHeader("DDR3L SPD Tool");
  lcd.setFont(FONT_MD);
  lcd.drawStr(10, 32, "No module found.");
  lcd.drawStr(8,  46, "Insert DDR3L...");
  lcd.sendBuffer();
}
void screenReading() {
  lcd.clearBuffer();
  drawHeader("DDR3L SPD Tool");
  lcd.setFont(FONT_MD);
  lcd.drawStr(18, 40, "Reading SPD...");
  lcd.sendBuffer();
}
void screenInfo(const uint8_t *s) {
  lcd.clearBuffer();
  drawHeader("DDR3L Module Info");
  char buf[24];
  lcd.setFont(FONT_MD);
  snprintf(buf, sizeof(buf), "Speed: %5u MT/s", tckToMTps(s[SPD_TCK_MIN]));
  lcd.drawStr(0, 25, buf);
  snprintf(buf, sizeof(buf), "Size : %5u MB",   calcCapMB(s));
  lcd.drawStr(0, 36, buf);
  snprintf(buf, sizeof(buf), "CL %2u  tRCD %2u  tRP %2u",
           s[SPD_TAA_MIN], s[SPD_TRCD_MIN], s[SPD_TRP_MIN]);
  lcd.drawStr(0, 47, buf);
  lcd.setFont(FONT_XS);
  const char *vlt = (s[SPD_VOLTAGE] & 0x02) ? "DDR3L 1.35V" : "DDR3  1.5V ";
  snprintf(buf, sizeof(buf), "%s  Slide>edit", vlt);
  lcd.drawStr(0, 62, buf);
  lcd.sendBuffer();
}
void screenEdit(int selParam) {
  lcd.clearBuffer();
  drawHeader("Edit  [ROT=val BTN1=param]");
  lcd.setFont(FONT_MD);
  int startIdx = constrain(selParam - 1, 0, N_PARAMS - 4);
  for (int i = startIdx; i < min(startIdx + 4, N_PARAMS); i++) {
    int  y   = 24 + (i - startIdx) * 11;
    bool sel = (i == selParam);
    if (sel) {
      lcd.drawBox(0, y - 9, 128, 11);
      lcd.setDrawColor(0);
    }
    char line[24];
    bool changed = (spdEdit[PARAMS[i].idx] != spdOrig[PARAMS[i].idx]);
    snprintf(line, sizeof(line), "%-11s %3d%s",
             PARAMS[i].label,
             spdEdit[PARAMS[i].idx],
             changed ? "*" : " ");
    lcd.drawStr(1, y, line);
    lcd.setDrawColor(1);
  }
  lcd.setFont(FONT_XS);
  lcd.drawStr(0, 63, "PRESS:edit val  HOLD 3s:write");
  lcd.sendBuffer();
}
void screenValue(int selParam) {
  lcd.clearBuffer();
  lcd.setFont(FONT_MD);
  lcd.drawStr(0, 10, PARAMS[selParam].label);
  lcd.drawHLine(0, 12, 128);
  uint8_t v = spdEdit[PARAMS[selParam].idx];
  char    buf[16];
  lcd.setFont(FONT_LG);
  snprintf(buf, sizeof(buf), "%3d", v);
  lcd.drawStr(34, 46, buf);
  lcd.setFont(FONT_XS);
  if (PARAMS[selParam].idx == SPD_TCK_MIN) {
    snprintf(buf, sizeof(buf), "= %u MT/s", tckToMTps(v));
    lcd.drawStr(36, 60, buf);
  } else {
    snprintf(buf, sizeof(buf), "orig: %d", spdOrig[PARAMS[selParam].idx]);
    lcd.drawStr(36, 60, buf);
  }
  lcd.drawStr(0, 63, "ROT:chg  PRESS:ok  BTN1:nxt");
  lcd.sendBuffer();
}
void screenConfirm() {
  lcd.clearBuffer();
  drawHeader("Confirm Write");
  lcd.setFont(FONT_MD);
  lcd.drawStr(4, 28, "Hold ROT 3s to write.");
  lcd.drawStr(4, 42, "Hold BTN2   to abort.");
  lcd.setFont(FONT_XS);
  lcd.drawStr(0, 63, "Changes marked with * will save");
  lcd.sendBuffer();
}
void screenWriting() {
  lcd.clearBuffer();
  drawHeader("Writing SPD...");
  lcd.setFont(FONT_MD);
  lcd.drawStr(10, 36, "Do not remove");
  lcd.drawStr(18, 50, "the module!");
  lcd.sendBuffer();
}
void screenDone(bool ok) {
  lcd.clearBuffer();
  drawHeader(ok ? "Write OK!" : "Write Failed!");
  lcd.setFont(FONT_MD);
  if (ok) {
    lcd.drawStr(10, 34, "SPD updated.");
    lcd.drawStr(4,  50, "Reinsert module.");
  } else {
    lcd.drawStr(4,  34, "Check connection");
    lcd.drawStr(4,  50, "and try again.");
  }
  lcd.sendBuffer();
}
void screenError() {
  lcd.clearBuffer();
  drawHeader("Read Error");
  lcd.setFont(FONT_MD);
  lcd.drawStr(8, 34, "SPD read failed!");
  lcd.drawStr(4, 50, "Check module.");
  lcd.sendBuffer();
}
enum State {
  S_NO_DDR,
  S_READING,
  S_INFO,
  S_EDIT,
  S_VALUE,
  S_WRITE_CONFIRM,
  S_WRITING,
  S_ERROR
};
State state     = S_NO_DDR;
int   curParam  = 0;

//     SETUP
void setup() {
  Serial.begin(115200);
  pinMode(PIN_ROT_A,     INPUT_PULLUP);
  pinMode(PIN_ROT_B,     INPUT_PULLUP);
  pinMode(PIN_ROT_SW,    INPUT_PULLUP);
  pinMode(PIN_BTN_SEL,   INPUT_PULLUP);
  pinMode(PIN_BTN_ABORT, INPUT_PULLUP);
  pinMode(PIN_SLIDE1,    INPUT_PULLUP);
  pinMode(PIN_SLIDE2,    INPUT_PULLUP);
  pinMode(PIN_WE,        OUTPUT);
  digitalWrite(PIN_WE,   HIGH);  
  attachInterrupt(digitalPinToInterrupt(PIN_ROT_A), rotISR, CHANGE);
  attachInterrupt(digitalPinToInterrupt(PIN_ROT_B), rotISR, CHANGE);
  spdBus.begin(SDA_SPD, SCL_SPD, 100000UL);
  lcd.begin();
  lcd.setContrast(200);
  screenNoDDR();
}

//            LOOP

void loop() {
  btnSel.update();
  btnAbort.update();
  btnRot.update();
  int rd = rotDelta();
  static State        prevState    = (State)255;
  static unsigned long pollTimer   = 0;
  bool redraw = (state != prevState);
  prevState   = state;
  auto editUnlocked = []() { return digitalRead(PIN_SLIDE2) == LOW; };
  switch (state) {
    case S_NO_DDR:
      if (redraw) screenNoDDR();
      if (millis() - pollTimer > 500) {
        pollTimer = millis();
        if (spdDetect()) state = S_READING;
      }
      break;
    case S_READING:
      screenReading();
      delay(30);
      if (spdRead(spdOrig)) {
        memcpy(spdEdit, spdOrig, SPD_SIZE);
        curParam = 0;
        state    = S_INFO;
      } else {
        state = S_ERROR;
      }
      break;
    case S_INFO:
      if (redraw) screenInfo(spdOrig);
      if (millis() - pollTimer > 1000) {
        pollTimer = millis();
        if (!spdDetect()) { state = S_NO_DDR; break; }
      }
      if (editUnlocked() && btnRot.wasPressed) {
        memcpy(spdEdit, spdOrig, SPD_SIZE);   
        curParam = 0;
        state    = S_EDIT;
      }
      break;
    case S_EDIT:
      if (!editUnlocked()) { state = S_INFO; break; }   
      if (rd != 0) {
        curParam = constrain(curParam + (rd > 0 ? 1 : -1), 0, N_PARAMS - 1);
        redraw   = true;
      }
      if (btnSel.wasPressed) {      
        curParam = (curParam + 1) % N_PARAMS;
        redraw   = true;
      }
      if (btnRot.wasPressed) {        
        state = S_VALUE;
        break;
      }
      if (btnRot.heldFor(3000)) {     
        state = S_WRITE_CONFIRM;
        break;
      }
      if (redraw) screenEdit(curParam);
      break;
    case S_VALUE:
      if (!editUnlocked()) { state = S_INFO; break; }
      if (rd != 0) {
        int v = (int)spdEdit[PARAMS[curParam].idx] + rd * (int)PARAMS[curParam].step;
        spdEdit[PARAMS[curParam].idx] =
            (uint8_t)constrain(v, PARAMS[curParam].minV, PARAMS[curParam].maxV);
        redraw = true;
      }
      if (btnSel.wasPressed) {       
        curParam = (curParam + 1) % N_PARAMS;
        redraw   = true;
      }
      if (btnRot.wasPressed) {       
        state = S_EDIT;
        break;
      }
      if (btnRot.heldFor(3000)) {   
        state = S_WRITE_CONFIRM;
        break;
      }
      if (redraw) screenValue(curParam);
      break;
    case S_WRITE_CONFIRM: {
      if (redraw) screenConfirm();
      if (btnAbort.heldFor(800)) {
        state = S_EDIT;
        break;
      }
      static unsigned long freshHoldStart = 0;
      static bool          waitRelease    = true;
      if (redraw) { freshHoldStart = 0; waitRelease = true; }
      bool rotDown = btnRot.isDown();
      if (waitRelease) {
        if (!rotDown) waitRelease = false;   
      } else {
        if (rotDown && freshHoldStart == 0)  freshHoldStart = millis();
        if (!rotDown)                        freshHoldStart = 0;
        if (freshHoldStart && millis() - freshHoldStart >= 3000) {
          freshHoldStart = 0;
          state          = S_WRITING;
        }
      }
      break;
    }
    case S_WRITING: {
      screenWriting();
      digitalWrite(PIN_WE, LOW);   
      delay(10);
      bool ok = spdWriteChanges(spdOrig, spdEdit);
      delay(10);
      digitalWrite(PIN_WE, HIGH);   
      if (ok) memcpy(spdOrig, spdEdit, SPD_SIZE); 
      screenDone(ok);
      delay(3500);
      state = S_INFO;
      break;
    }
    case S_ERROR:
      if (redraw) screenError();
      if (millis() - pollTimer > 2500) {
        pollTimer = millis();
        state     = S_NO_DDR;
      }
      break;
  }
  delay(8);   
}

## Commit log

2026-06-09 added BOM
    [BOM.csv]
2026-06-09 Enhance README with assembly details and images
    Expanded the README to include assembly options and images.
2026-06-16 added CAD file
2026-06-16 added CAD files
    [DDR3 tester PCB.step]
2026-07-15 added updated CAD files
2026-07-30 added top.step and bottom.step
    [Bottom.step, Top.step]
2026-07-30 Enhance README with assembly and flashing details
    Added assembly and flashing instructions to README.
2026-07-30 added new lcsc bom
    [BOM_lcsc.csv]
2026-07-30 added updated lcsc bom
    [BOM_lcsc.csv]
